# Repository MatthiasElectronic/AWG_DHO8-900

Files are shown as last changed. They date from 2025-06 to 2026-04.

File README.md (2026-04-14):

Artificial Waveform Generator for DHO800 and DHO900 series
===

This is a daughter board for the Rigol DHO800 or DHO900 series oscilloscopes to add the missing hardware for the function generator.  
State: finished and working

[Download all files as zip archive here](https://github.com/MatthiasElectronic/AWG_DHO8-900/archive/refs/heads/main.zip)

Discussion thread: https://www.eevblog.com/forum/testgear/awg-function-generator-for-dho800-900-series-oscilloscopes/

Hands-On video by Thomas from "hochohmig": https://www.youtube.com/watch?v=W03NUFdP6oc

Top_View
bottom_view
Overview

Table of Contents
===
1. [Target of this project](#target-of-this-project)
2. [Versions](#versions)
3. [Performance](#performance)
4. [Requirements](#requirements)
5. [Cost and Ordering](#cost-and-ordering)
6. [Interface between Mainboard and AWG daughter board](#interface-between-mainboard-and-awg-daughter-board)
7. [Topology discussion and design decisions](#topology-discussion-and-design-decisions)
8. [Possible Improvements](#possible-improvements)
9. [Thanksgiving](#thanksgiving)
10. [Disclaimer](#disclaimer)

Target of this project
-------
1. This is NOT a copy of the original function generator, but it uses the same interface and same DAC.
2. This design is optimized for cheap production including assembly, by the minimizing the amount of "extended components" from the JLCPCB manufacturer.
3. Minimizing distortion (THD) and noise (SNR) is achieved.
4. The ADC output filter is designed for better pulse and step response, therby having worse anti-alias attenuation (for >10MHz signals) and slight passband signal attenuation
5. Gain and offset tolerances are worse. A significant contributor is anyhow on the oscilloscope mainboard, so perfection cannot be achieved. However, if unlucky, tolerances in this project can mathematically hit quite hard.
6. As the original AWG, this function generator is designed for a 50 OHm coax cable with high impedance termination.

Versions
-------
V1: Original version, not recommended due to an offset bug and smaller mechanical misalignments.  
V2: Second version, not recommended due to a bug with OPA2673 sometimes getting hot. The fix with V3 is to connected Pins A0 and A1 to GND instead of -6.5V.  
V3: Recommended version.  
More details are in the history page in the schematic.

Performance
---
All signals are created with this AWG board, mounted on a DHO804 with a DHO924S vendor.bin.  
Measured on V1 PCB with the modifications of the V2 schematic.  

### Switching edges of a rectangular waveform
The switching edges are clean. trise & tfall are 15.5ns. This is a picture of maximum amplitude (+/-5V), but rise and fall times were measured identical for smaller voltages.  
Rect

### Bandwidth
The -3dB point is slightly above 25MHz. At the maximum selectable frequency of 25MHz, a peak-to-peak voltage of 719mV is measured, which is just above the 707mV of the -3dB point.  
Bandwidth

### Distortion / THD
Distortion is over the most parts independent from the amplitude, just at very small amplitudes this is different.  
Here, a measurement of a 1kHz sine signal at 10V and 100mV peak-to-peak voltage is provided.  
At 10Vpp, the dominant HD3 is at ca. -62dB, so THD should be below -60dB.  
Distortion_10V
Distortion_100mV

### Noise / SNR
**Noise measurement setup:**  
A sine signal at very low frequency is applied, the trigger is set to the crossover and the horizontal range is small such that the signal appears as DC.  
→ This way, AC RMS can be measured and equals the RMS noise at that signal amplitude. However, ultra low frequency noise is not visible.

**Noise at 2Vpp signal amplitude:**  
Noise_2V_Coax  
Noise RMS = 334µV, Signal RMS = 707mV => SNR = 67dB

**Noise at 10Vpp signal amplitude:**  
Noise_AWG_On_10V  
Noise RMS = 5.2mV, Signal RMS = 3.54V => SNR = 57dB

**Noise source**  
The measured noise levels are dominated by ripples/spikes from radiated EMI of the switching requlators on the mainboard with unshielded inductors.  
A 1.3MHz ripple is always present.  
A 740kHz ripple is only visible for >2Vpp, when the x10 gain stage (relay K4) is active..  
In the following FFT of a 10Vpp 1MHz sine signal, both ripples appear as peaks:  
Ripple_740kHz  
Luckily, this is coupled into the circuit before the attenuators, so at smaller signal amplitudes also the EMI ripple is attenuated.

In addition, there are random (burst mode) spikes clearling coming from the PSU brick. They can even be measured with the AWG switched off.  
Outside_Noise_Incoupling  

**To clarify: The noise/ripple is small enough, it is not visible in time domain unless having a very small amplitude.**

### Gain and Offset accuracy
My prototype has -3mV DC offset, coming directly from the motherboard on the target "DC offset" pin. This is the most noticable offset error, because this one is fully visible at the smallest signal amplitudes.  
Fixed this for my board, but this is completely related to tolerance. Additional offset errors are given in dependency of the AC gain and range selection, also this is amplified by 10 when the output signal exceeds 1Vp.  

My oscilloscope mainboard has a gain error of 3% between highest and lowest gain reference value. This is the most dominant part of the gain error, so if there is a need to fix this tolerance, this has to be done specific for each oscilloscope.

Requirements
--------
**Change vendor.bin**  
To add this AWG to the oscilloscope, a modified vendor.bin (DHO914S or DHO924S) to enable the AWG software functionalities is required.
https://www.eevblog.com/forum/testgear/hacking-the-rigol-dho800900-scope/msg5344076/#msg5344076

**Offset Removal**  
After modifying the vendor.bin, a DC offset in the analog measurement channels is there and might even not be removable by recalibration.  
A firmware update AFTER changing the vendor.bin, followed by a recalibration helps. I assume that the FPGA fimware is changed during a firmware update in dependency of the vendor.bin.

**Hardware version resistors**  
Update: There is no need to change the resistors for version detection - both DHO800 and DHO900 series oscilloscopes work without changing resistors.

**Add missing components to the mainboard**  
The DHO800 series oscilloscopes are missing some parts on the mainboard.  
- The connectors (1.27mm female sockets) 2x20 and 2x5 have to be added (this might be helpful, thanks to Mechatrommer: https://www.youtube.com/watch?v=dBg6KQtSWTM)
- Two OP Amps (3PEAK TP1282L1-VR) have to be added for the offset and gain analog values. These are not really suited for this operation (because they are not officially input rail-rail), but somehow this still works and they are also placed on the original DHO900 series.
- The BNC connector is missing, but as this part is extremely high and nowhere to find, I instead increased the AWG PCB size and simply mounted a smaller BNC connector on the AWG board. So no extra BNC connector on the mainboard. When soldering the BNC connector onto the daughterboard, I suggest to do this as the last step. The SMD PCB interconnects have some tolerance and also the BNC connector ideally should not be pushed completely into the PCB to achieve the same height as the "trigger out" from the mainboard. I aligned the connector before soldering with the AWG daughterboard mounted on the mainboard.
- The board needs to be fixed to the mounting holes. M4 screws with two M4 fasteners were sufficient, but are slightly too large (soldermask IS the isolation...). A better solution (idea from hochohmig.de) are solderable M3 through hole taps, this is cleaner and does not require access to the backside of the mainboard. Securing the daughterboard to the mainboard with the mounting holes is absolutely necessary, the PCB interconnects alone are not sufficient as the BNC connector is not fastened to the case.
- A hole needs to be drilled in the plastic casing for the BNC connector.  
unplaced
OP_AMPs
placed  
BNC_inside
BNC_outside
through_hole_tap

Luckily, all remaining components (resistors, reference voltages, digital interface, …) are already assembled.

**It is NOT necessary to add any additional RAM to the DHO800 series.**

Cost and Ordering
-------
Total cost for 1 board should be ca. 50€.

All components (apart from the connectors) are soldered on the top layer. The PCB is a four layer board.  
This allowed economic assembly with JLCPCB (not sponsored), which is very cheap when using the preferred components. So the whole design is optimized around these preferred components to keep cost low. However, there are some components that are extended (and this costs ca. 3€ each extra). So most of them were ordered on LCSC, because this order was anyways necessary for the connectors and the OP-Amps on the main board.
All parts in this design files have a LCSC number, which makes ordering at LCSC or JLCPCB very simple.
Just be sure that you
1. Have a hot air station or let the QFN packages be soldered (DAC & OP-Amp). Even when ignoring the bottom central GND-pad, this won’t be easy with a simple soldering iron.
2. Use a four layer bord with the recommended or a similar stackup as documented on the first page of the schematic to have somewhat correct impedances.
3. Have accessable vias such that you can use them as measurement points if something does not work.
4. Do not choose a different inductor with a larger height for the step down converters, as there is no space to the casing.

When keeping extended components low (I only chose the SMD inductor), then this can be quite cheap. I ended up with 34€ on JLCPCB for 5 partly assembled boards and 41€ on LCSC for components for 2 boards, including tax and shipment. This adds up to 75€. It should be ca. 53€ if I only ordered components for 1 board. (05/2025)

Interface between Mainboard and AWG daughter board
----
CLK = Sample rate = 156MHz  
The digital data is ALWAYS completely using up the headroom of the DAC.  
Adjustments on the gain are only done by the analog gain input voltage, not digitally.  
With Amplitude = Vpp set to 2V, all attenuation/amplification stages K1-K4 are disabled and the analog gain input is at its maximum value.  
Still unclear is the "Protection" output signal, also it seems strange that this has to be pulled down to negative voltage.  
The 5 relays are: /sqrt(10), /10, /10, *10, On/Off

Topology discussion and design decisions
---
The topolology is  
Topology_updated

The DAC itself is the same as on the original AWG board, but in a much cheaper QFN package. The allowed DAC output current was significantly overdriven in the original design, thus I reduced this current.

The OP amps are completely exchanged in favor for the price. The original 1GHz part just seemed to be overkill for a 50MHz signal generator. I chose the 230MHz OPA2673 instead. Sadly, there is nothing cheap in between that has high voltage and high bandwith. But the slew rate is sufficient.

Power rails are reduced to only +6.5V and -6.5V, which is just sufficient for the maximum +5V / -5V signal output voltage and at the border of the allowed OP amp operating conditions. These are both switchers, ripple is kept low by having forced PWM and filtering directly at the OP amp inputs. There is no need for LDOs as most LDOs cannot remove the 1.1MHz ripple. The 5V relays are rated for this voltage, so this is great as well.
Although the original board had +15V/-12V, the same maximum output signal is achieved. Having only 6.5V means that the DC offset stage had to be redone, therefore all PI attenuators and OP amp gains had to be changed. As an easy addon, I also added matched impedances on the PCB.

The DAC output filter is completly redone. The original filter required very specific and uncommon component values, which are nowhere availlable, so this had to be completely changed.

In the original design there was a 9th oder elliptic filter, which sounds great for HF suppression, but has a terrible step response. As I wanted solid edges for rectangular signals, I opted for a filter with a much better phase. While also optimizing for minimum component variation, this turned out to be a bit „creative“ and a 5th order lowpass filter (somewhere in between butterworth and bessel). Simulation in Spice looked promising, but the measured edges (see above, trise/fall = 15.5ns) are slightly slower than simulated (10ns).

As can be seen below, the step response is much better while not exceeding the OP ampl slew rate. Looking at the attenuation over frequency, obviously the elliptic filter is better. My filter has a slight attenuation in the upper passband and a not so perfect attenuation at the sample frequency (156MHz).

Attenuation in the passband: This is noticable for frequencies above 10MHz, but can be corrected for sine signals by manually adjusting the amplitude.

Aliasing: Aliasing can only occur above the Nyquist frequency (78MHz). For signals with lower frequencies (e. g. <1MHz), where fsig << fsample, this is not important as the sinc-behavior in the frequency domain of the sample and hold circuit does sufficently suppress any aliasing (sinc(1-1MHz/156MHz)=-44dB), in addition to the lowpass attenuation. For larger frequencies, this will be worse and probably noticable in the FFT or a spectrum viewer.

Conclusion:  
→ a worse aliasing attenuation, relevant only at high frequencies
→ a better behavior in the step and impulse response

filter

Possible Improvements
---
...which I am not going to solve, but feel free to contribute.  
- the M4 fasteners are too large, more space is required as the solder mask is currently the only line of defence.  
- a DC offset potentiometer would be helpful  
- improve the gain accuracy, but this can get very difficult  
- choose connectors with through-hole alignment pins for easier assembly, but this might require better measurement of the dimensions.
- Eliminate the magnetic EMI incoupling of the switching regulators on the mainboard. Easiest solution could be swapping layer 3 (GND) and layer 4 (signal) and correcting trace widths for the impedances.
  However, as this is magnetic near field, this might not be sufficent. I tried some aluminum kitchen foil connected to GND as a shield, which brought -3dB. A floating thin iron sheet brought -10dB.
  Another option could be to replace the unshielded inductors on the main board with shielded ones.

Be warned that on the left hand side from the relays, the plastic case gets very close to the PCB, so even large MLCCs or SMD inductors can be too large and the relays definitly are.

Thanksgiving
---
Thanks to  
Everybody contributing to the [Hacking the Rigol DHO800/900 Scope](https://www.eevblog.com/forum/testgear/hacking-the-rigol-dho800900-scope/) thread  
Pu6k1n [EEVBlog] for the [schematic of the reverse-engineered original AWG](https://www.eevblog.com/forum/testgear/hacking-the-rigol-dho800900-scope/?action=dlattach;attach=2492911), the pinning helped a lot  
AndyBig [EEVBlog] for all information about DHO800 to DHO900 vendor.bin modification and reporting a bug with V2  
Mechatrommer [EEVBlog] for inspiration from his own AWG attempt and lots of tiny information  
Thomas from [hochohmig.de](https://www.hochohmig.de/) for providing calculation tools, testing the board and creating a [demonstration video - check out his channel](https://www.youtube.com/watch?v=W03NUFdP6oc&t=1s)  
Contributers to KiCad and the library plugins

Disclaimer
---
This is published with CERN-OHL-W-2.0 license, which is accessible in license.txt.
No liability is provided for this not working or causing any form of damage or harm. This is not a product, but a development board. Use at your own risk.  
This project is influenced by the original AWG from Rigol, so only recommended for personal use. Although not checked, selling this AWG could possibly violate patents or rights of Rigol.

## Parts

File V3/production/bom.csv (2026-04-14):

Designator | Footprint | Quantity | Value | LCSC Part #
C201, C202, C203, C209, C210, C305, C310, C312, C313, C315, C321, C323, C324, C325, C326, C328, C401, C404, C405, C501, C505 | C_0603 | 21 | 100nF | C14663
C204, C205, C206, C211, C212, C213, C304, C309, C311, C314, C322, C327, C402, C403 | C_0805 | 14 | 10uF | C15850
C207, C208, C214, C215, C216, C217 | C_1206 | 6 | 47uF | C96123
C301, C302 | C_0603 | 2 | 10pF | C1634
C303, C306 | C_0603 | 2 | 68pF | C28262
C317, C318, C320, C329 | C_0603 | 4 | 100pF | C14858
C406, C409, C410, C411, C412, C413, C502, C503 | C_0603 | 8 | 1uF | C15849
C407, C408, C504 | C_0603 | 3 | 47pF | C1671
D301, D302, D401, D402, D403, D404, D405, D406, D407, D408, D501 | SOT-23-3_L2.9-W1.3-P1.90-LS2.4-BR | 11 | BAV99_C7420336 | C7420336
FB201, FB202, FB203 | FB_0805 | 3 | ~ | C1015
J101 | BNC_Amphenol_ICC 031-5329-51RFX | 1 | BNC_Amphenol_ICC 031-5329-51RFX | C5443992
K1, K2, K3, K4, K5 | RELAY-SMD_G6K-2F-X-XX | 5 | ~ | C47190
L201, L202 | L_APV_ANR5045 | 2 | 22uH | C440232
L301, L302, L303, L304, L305, L306, L307, L308, L309, L310, L311, L401 | L_0603 | 12 | 100nH | C98088
Q201, Q301 | Q_SOT-23 | 2 | MMBT3906 | C7420354
Q202, Q401, Q402, Q403, Q404, Q405 | Q_SOT-23 | 6 | BC846B | C20069134
R101, R504 | R_0603 | 2 | 1kΩ | C21190
R103 | R_0603 | 1 | 0Ω | C21189
R201, R207 | R_0603 | 2 | 24kΩ | C23352
R202, R205, R206, R210, R212, R435, R436, R440, R441, R442 | R_0603 | 10 | 22kΩ | C31850
R203, R208, R209, R408, R433, R434, R437, R438, R439, R502, R507 | R_0603 | 11 | 3.3kΩ | C22978
R204, R211, R318, R443, R444, R445, R446, R447 | R_0603 | 8 | 68Ω | C27592
R301, R406 | R_0603 | 2 | 4.7Ω | C23164
R302, R315 | R_0603 | 2 | 5.6kΩ | C23189
R303, R314, R427, R428 | R_0603 | 4 | 390Ω | C23151
R304, R430, R431 | R_0603 | 3 | 56Ω | C25196
R305, R311 | R_0603 | 2 | 49.9Ω | C23185
R306, R312, R316 | R_0603 | 3 | 2.7kΩ | C13167
R307, R310, R317, R319, R422, R423, R424, R425 | R_0603 | 8 | 100Ω | C22775
R308, R313 | R_0603 | 2 | 560Ω | C23204
R401, R419, R420 | R_0603 | 3 | 4.7kΩ | C23162
R402, R405, R409 | R_0603 | 3 | 15Ω | C22810
R403, R505, R508 | R_0603 | 3 | 100kΩ | C25803
R404 | R_0805 | 1 | 270Ω | C17590
R407 | R_0603 | 1 | 4.3kΩ | C23159
R410, R413 | R_1206 | 2 | 100Ω | C17901
R414, R415, R416, R417 | R_0603 | 4 | 10Ω | C22859
R418, R421, R432, R460 | R_0603 | 4 | 180Ω | C22828
R426 | R_0603 | 1 | 47Ω | C23182
R429 | R_0603 | 1 | 6.8kΩ | C23212
R455 | R_0603 | 1 | 82Ω | C23255
R457 | R_1206 | 1 | 120Ω | C17909
R458 | R_0603 | 1 | 1.8kΩ | C4177
R501, R506 | R_0603 | 2 | 3.9kΩ | C23018
R503 | R_0603 | 1 | 5.1kΩ | C23186
U201, U202 | SOT-23-6 | 2 | LMR54406FDBVR | C3193129
U301 | Texas_RSA_VQFN-16-1EP_4x4mm_P0.65mm_EP2.7x2.7mm | 1 | OPA2673IRGVR | C1848168
U302 | LFCSP-32_L5.0-W5.0-P0.50-BL-EP3.1 | 1 | AD9744ACPZRL7 | C514295
U303 | SOIC-8_L4.9-W3.9-P1.27-LS6.0-BL | 1 | NE5532DR | C7426
U501 | SOIC-8_3.9x4.9mm_P1.27mm | 1 | LM393DR2G | C7955
X1 | PinHeader_2x20_P1.27mm_Vertical_SMD | 1 | Conn_02x20_1.27mm_SMD_Header_M | C2881925
X2 | PinHeader_2x05_P1.27mm_Vertical_SMD | 1 | Conn_02x05_1.27mm_SMD_Header_M | C2881910

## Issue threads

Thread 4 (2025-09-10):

What is U302?

Kabron287, 2025-09-10:
What is U302?

MatthiasElectronic, 2025-09-14:
U302 is AD9744ACPZRL7.
It was not visible in the schematic, also not in the BOM. Thanks for the feedback, I just fixed that for V2.

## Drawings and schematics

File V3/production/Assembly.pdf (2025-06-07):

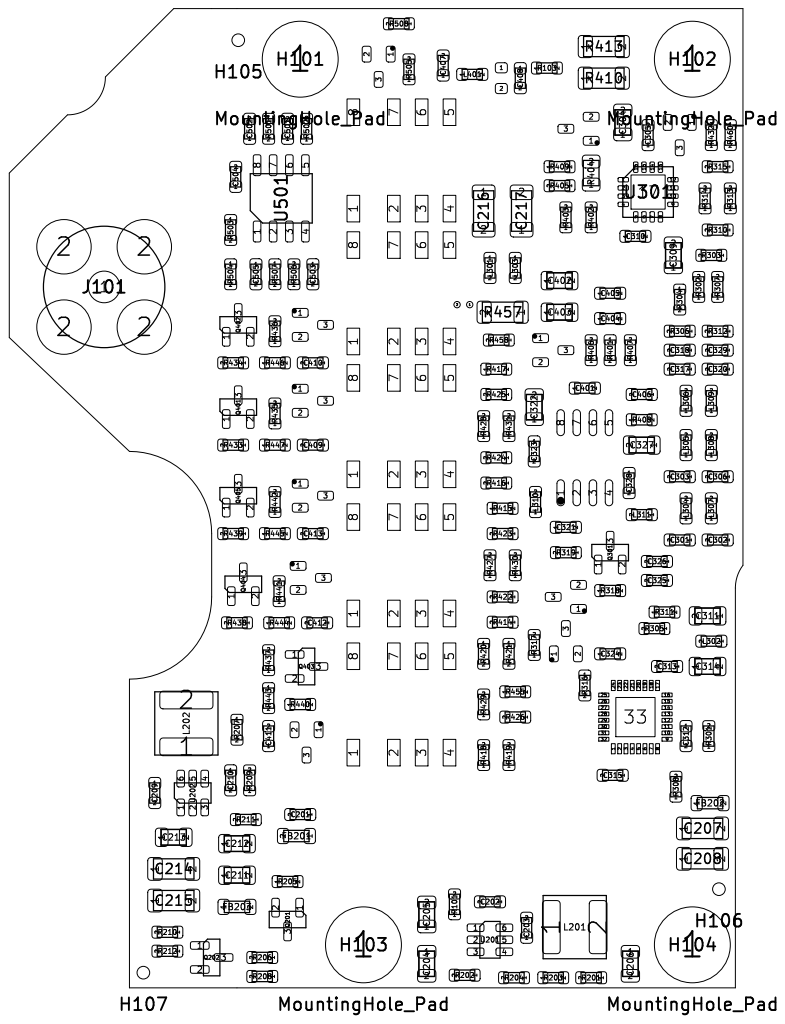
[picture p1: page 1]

File: AWG.kicad_pcb Sheet: M. Zimmermann

Id: 1/1 Title: AWG for DHO8/900

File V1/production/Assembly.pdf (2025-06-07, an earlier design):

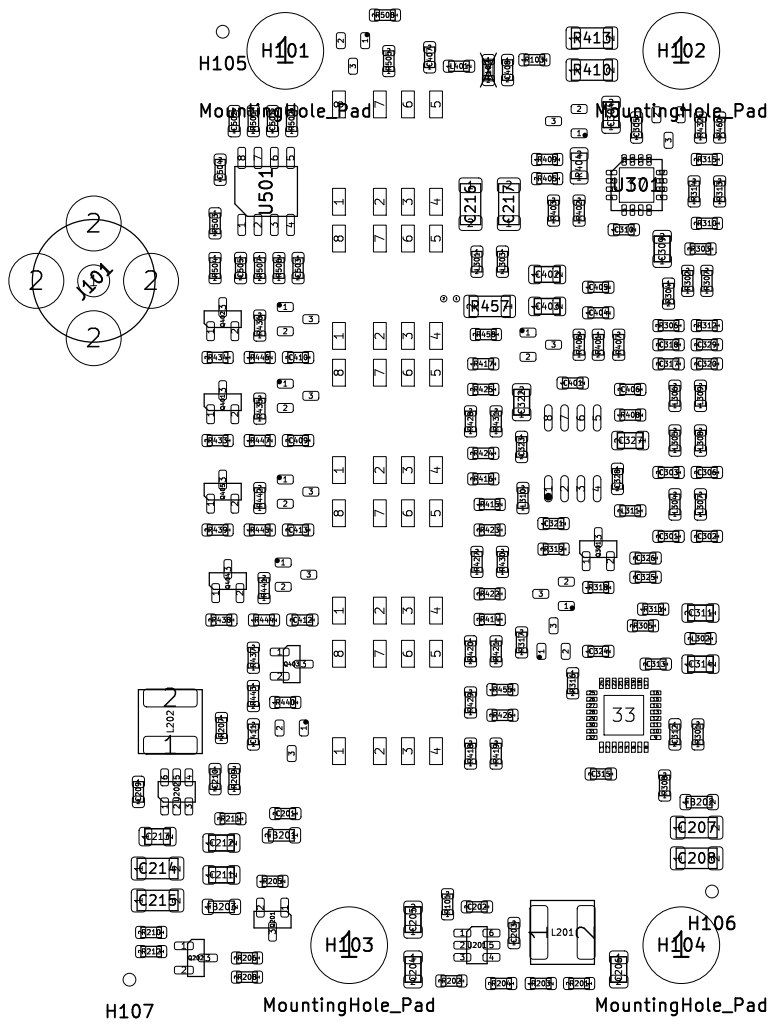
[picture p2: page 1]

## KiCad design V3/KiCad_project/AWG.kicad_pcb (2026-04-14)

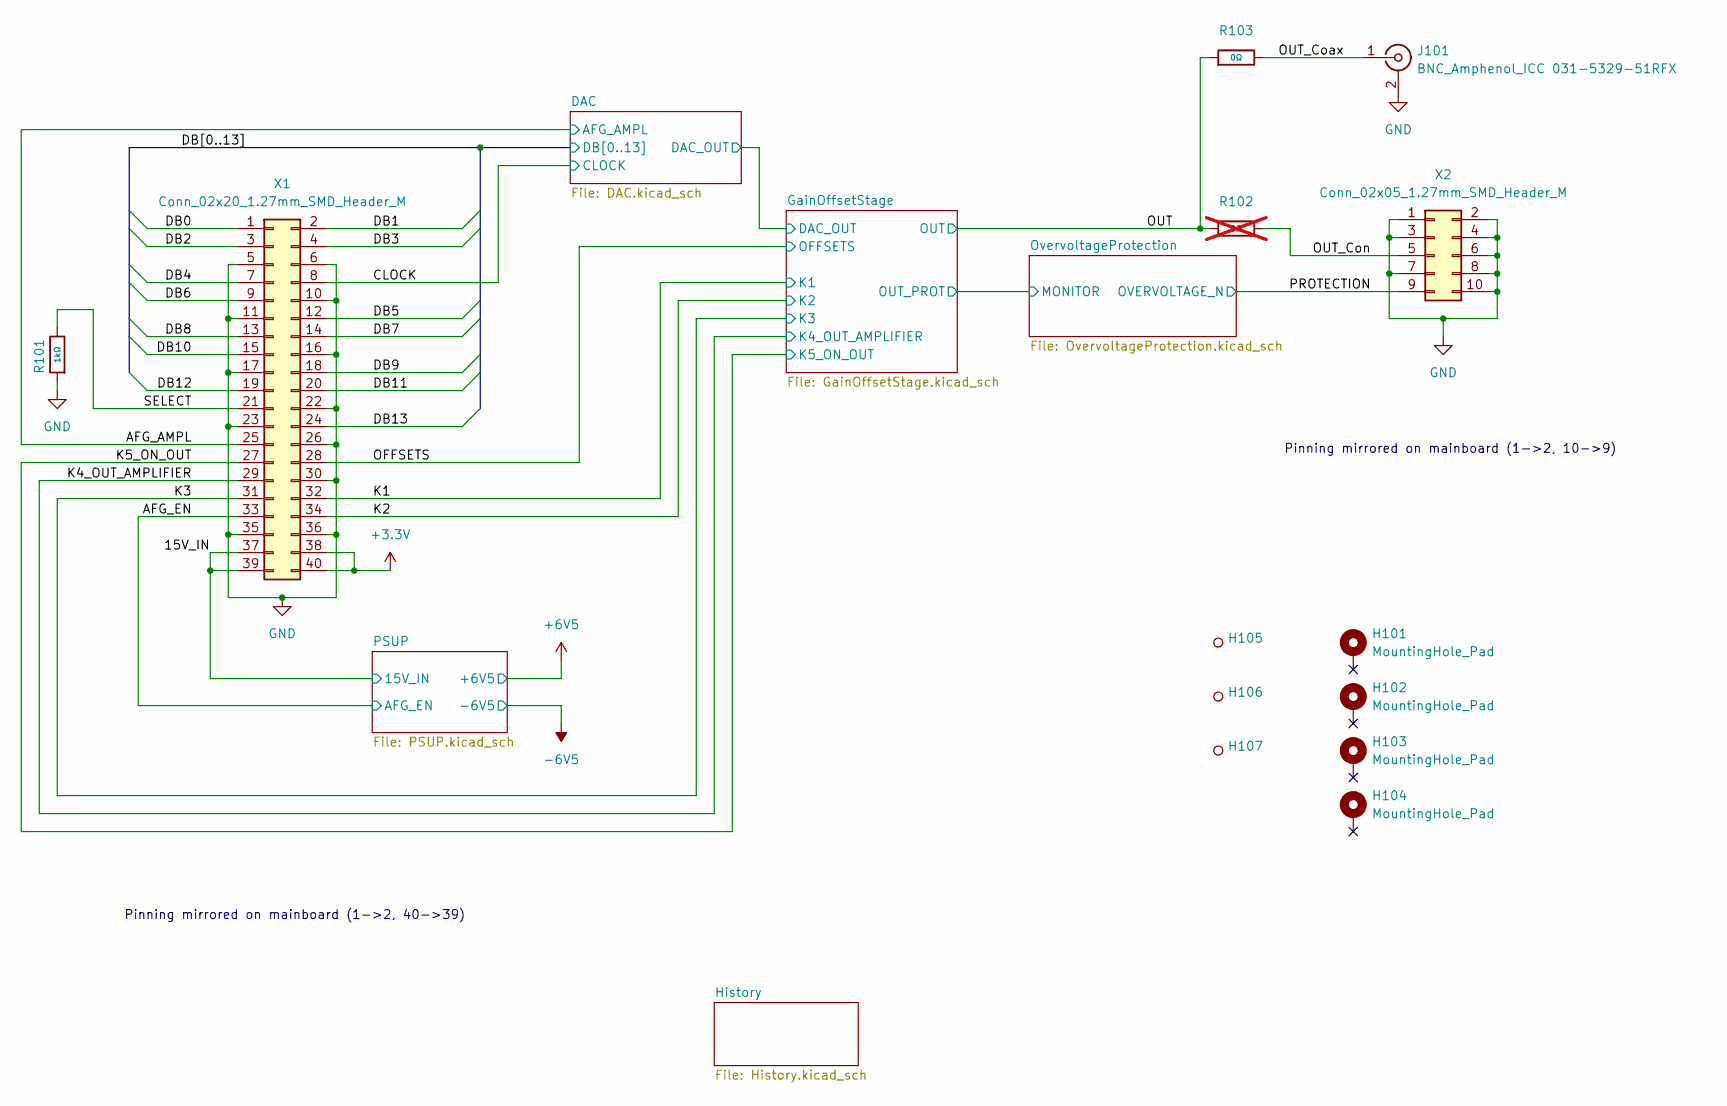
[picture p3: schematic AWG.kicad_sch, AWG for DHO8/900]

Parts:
H101, H102, H103, H104: MountingHole_Pad; MountingHole_4.0mm_SmallPad
H105, H106, H107: Hole_Tooling_JLCPCB
J101: BNC_Amphenol_ICC 031-5329-51RFX; LCSC C5443992
R101: 1kΩ; R_0603; Overload Voltage (Max) 75V; Tolerance ±1%; Part 0603WAF1001T5E; LCSC C21190
R102: 0Ω; R_0603; Overload Voltage (Max) 75V; Tolerance ±1%; Part 0603WAF0000T5E; LCSC C21189; not fitted
R103: 0Ω; R_0603; Overload Voltage (Max) 75V; Tolerance ±1%; Part 0603WAF0000T5E; LCSC C21189
X1: Conn_02x20_1.27mm_SMD_Header_M; PinHeader_2x20_P1.27mm_Vertical_SMD; LCSC C2881925
X2: Conn_02x05_1.27mm_SMD_Header_M; PinHeader_2x05_P1.27mm_Vertical_SMD; LCSC C2881910

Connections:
+3.3V: X1.38, X1.40; also elsewhere on the board
/15V_IN: X1.37, X1.39; also elsewhere on the board
/AFG_AMPL: X1.25; also elsewhere on the board
/AFG_EN: X1.33; also elsewhere on the board
/CLOCK: X1.8; also elsewhere on the board
/DB0: X1.1; also elsewhere on the board
/DB1: X1.2; also elsewhere on the board
/DB2: X1.3; also elsewhere on the board
/DB3: X1.4; also elsewhere on the board
/DB4: X1.7; also elsewhere on the board
/DB5: X1.12; also elsewhere on the board
/DB6: X1.9; also elsewhere on the board
/DB7: X1.14; also elsewhere on the board
/DB8: X1.13; also elsewhere on the board
/DB9: X1.18; also elsewhere on the board
/DB10: X1.15; also elsewhere on the board
/DB11: X1.20; also elsewhere on the board
/DB12: X1.19; also elsewhere on the board
/DB13: X1.24; also elsewhere on the board
/K1: X1.32; also elsewhere on the board
/K2: X1.34; also elsewhere on the board
/K3: X1.31; also elsewhere on the board
/K4_OUT_AMPLIFIER: X1.29; also elsewhere on the board
/K5_ON_OUT: X1.27; also elsewhere on the board
/OFFSETS: X1.28; also elsewhere on the board
/OUT: R102.1, R103.1; also elsewhere on the board
/OUT_Coax: J101.1 (In), R103.2
/OUT_Con: R102.2, X2.5
/PROTECTION: X2.9; also elsewhere on the board
/SELECT: R101.2, X1.21
GND: J101.2 (Ext), R101.1, X1.5, X1.6, X1.10, X1.11, X1.16, X1.17, X1.22, X1.23, X1.26, X1.30, X1.35, X1.36, X2.1, X2.2, X2.3, X2.4, X2.6, X2.7, X2.8, X2.10; also elsewhere on the board

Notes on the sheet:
Pinning mirrored on mainboard (1->2, 40->39)
Pinning mirrored on mainboard (1->2, 10->9)

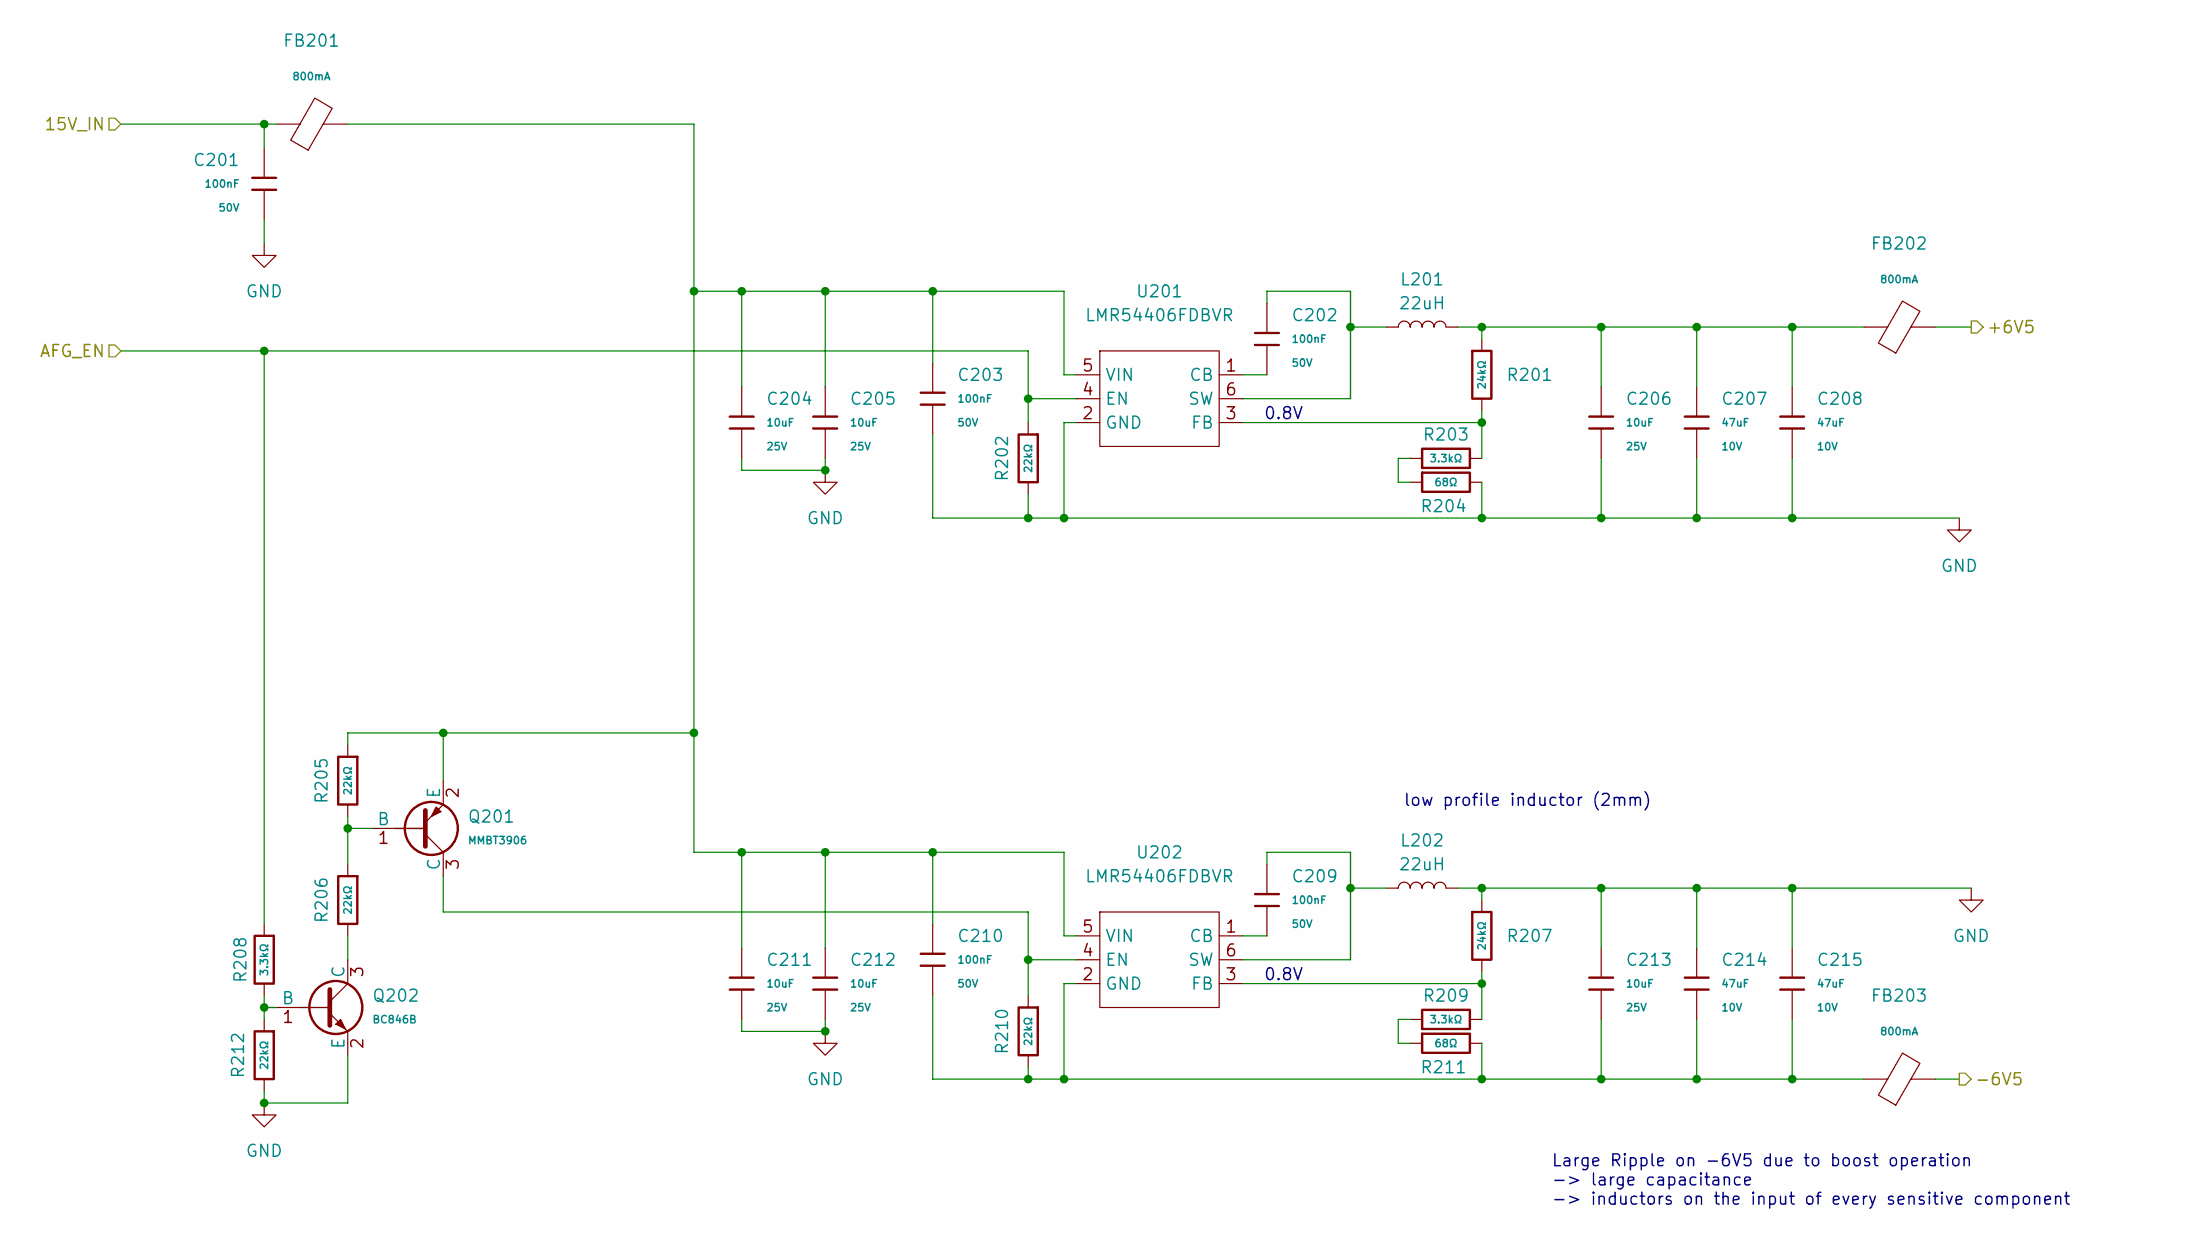
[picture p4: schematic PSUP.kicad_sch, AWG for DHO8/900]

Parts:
C201, C202, C203, C209, C210: 100nF; C_0603; Voltage Rated 50V; Tolerance ±10%; Part CC0603KRX7R9BB104; LCSC C14663
C204, C205, C206, C211, C212, C213: 10uF; C_0805; Voltage Rated 25V; Tolerance ±10%; Part CL21A106KAYNNNE; LCSC C15850
C207, C208, C214, C215: 47uF; C_1206; Voltage Rated 10V; Tolerance ±20%; Part CL31A476MPHNNNE; LCSC C96123
FB201, FB202, FB203: FB_0805; Current Rating 800mA; Tolerance ±25%; Part GZ2012D101TF; LCSC C1015
L201, L202: 22uH; L_APV_ANR5045; LCSC C440232
Q201: MMBT3906; Q_SOT-23; Part MMBT3906; LCSC C7420354
Q202: BC846B; Q_SOT-23; Part BC846B; LCSC C20069134
R201, R207: 24kΩ; R_0603; Overload Voltage (Max) 75V; Tolerance ±1%; Part 0603WAF2402T5E; LCSC C23352
R202, R205, R206, R210, R212: 22kΩ; R_0603; Overload Voltage (Max) 75V; Tolerance ±1%; Part 0603WAF2202T5E; LCSC C31850
R203, R208, R209: 3.3kΩ; R_0603; Overload Voltage (Max) 75V; Tolerance ±1%; Part 0603WAF3301T5E; LCSC C22978
R204, R211: 68Ω; R_0603; Overload Voltage (Max) 75V; Tolerance ±1%; Part 0603WAF680JT5E; LCSC C27592
U201, U202: LMR54406FDBVR; SOT-23-6; Manufacturer Part LMR54406FDBVR; LCSC C3193129

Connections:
+6V5: FB202.2; also elsewhere on the board
-6V5: FB203.2; also elsewhere on the board
/15V_IN: C201.1, FB201.1; also elsewhere on the board
/AFG_EN: R202.1, R208.1, U201.4 (EN); also elsewhere on the board
GND: C201.2, C203.2, C204.2, C205.2, C206.2, C207.2, C208.2, C211.2, C212.2, C213.1, C214.1, C215.1, L202.2, Q202.2 (E), R202.2, R204.2, R207.1, R212.2, U201.2 (GND); also elsewhere on the board
unnamed: C206.1, C207.1, C208.1, FB202.1, L201.2, R201.1
unnamed: Q201.1 (B), R205.2, R206.1
unnamed: Q201.3 (C), R210.1, U202.4 (EN)
unnamed: C203.1, C204.1, C205.1, C210.1, C211.1, C212.1, FB201.2, Q201.2 (E), R205.1, U201.5 (VIN), U202.5 (VIN)
unnamed: Q202.1 (B), R208.2, R212.1
unnamed: Q202.3 (C), R206.2
unnamed: R203.1, R204.1
unnamed: R209.1, R211.1
unnamed: C202.2, U201.1 (CB)
unnamed: R201.2, R203.2, U201.3 (FB)
unnamed: C202.1, L201.1, U201.6 (SW)
unnamed: C209.2, U202.1 (CB)
unnamed: R207.2, R209.2, U202.3 (FB)
unnamed: C210.2, C213.2, C214.2, C215.2, FB203.1, R210.2, R211.2, U202.2 (GND)
unnamed: C209.1, L202.1, U202.6 (SW)

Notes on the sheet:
0.8V
Large Ripple on -6V5 due to boost operation -> large capacitance -> inductors on the input of every sensitive component
low profile inductor (2mm)

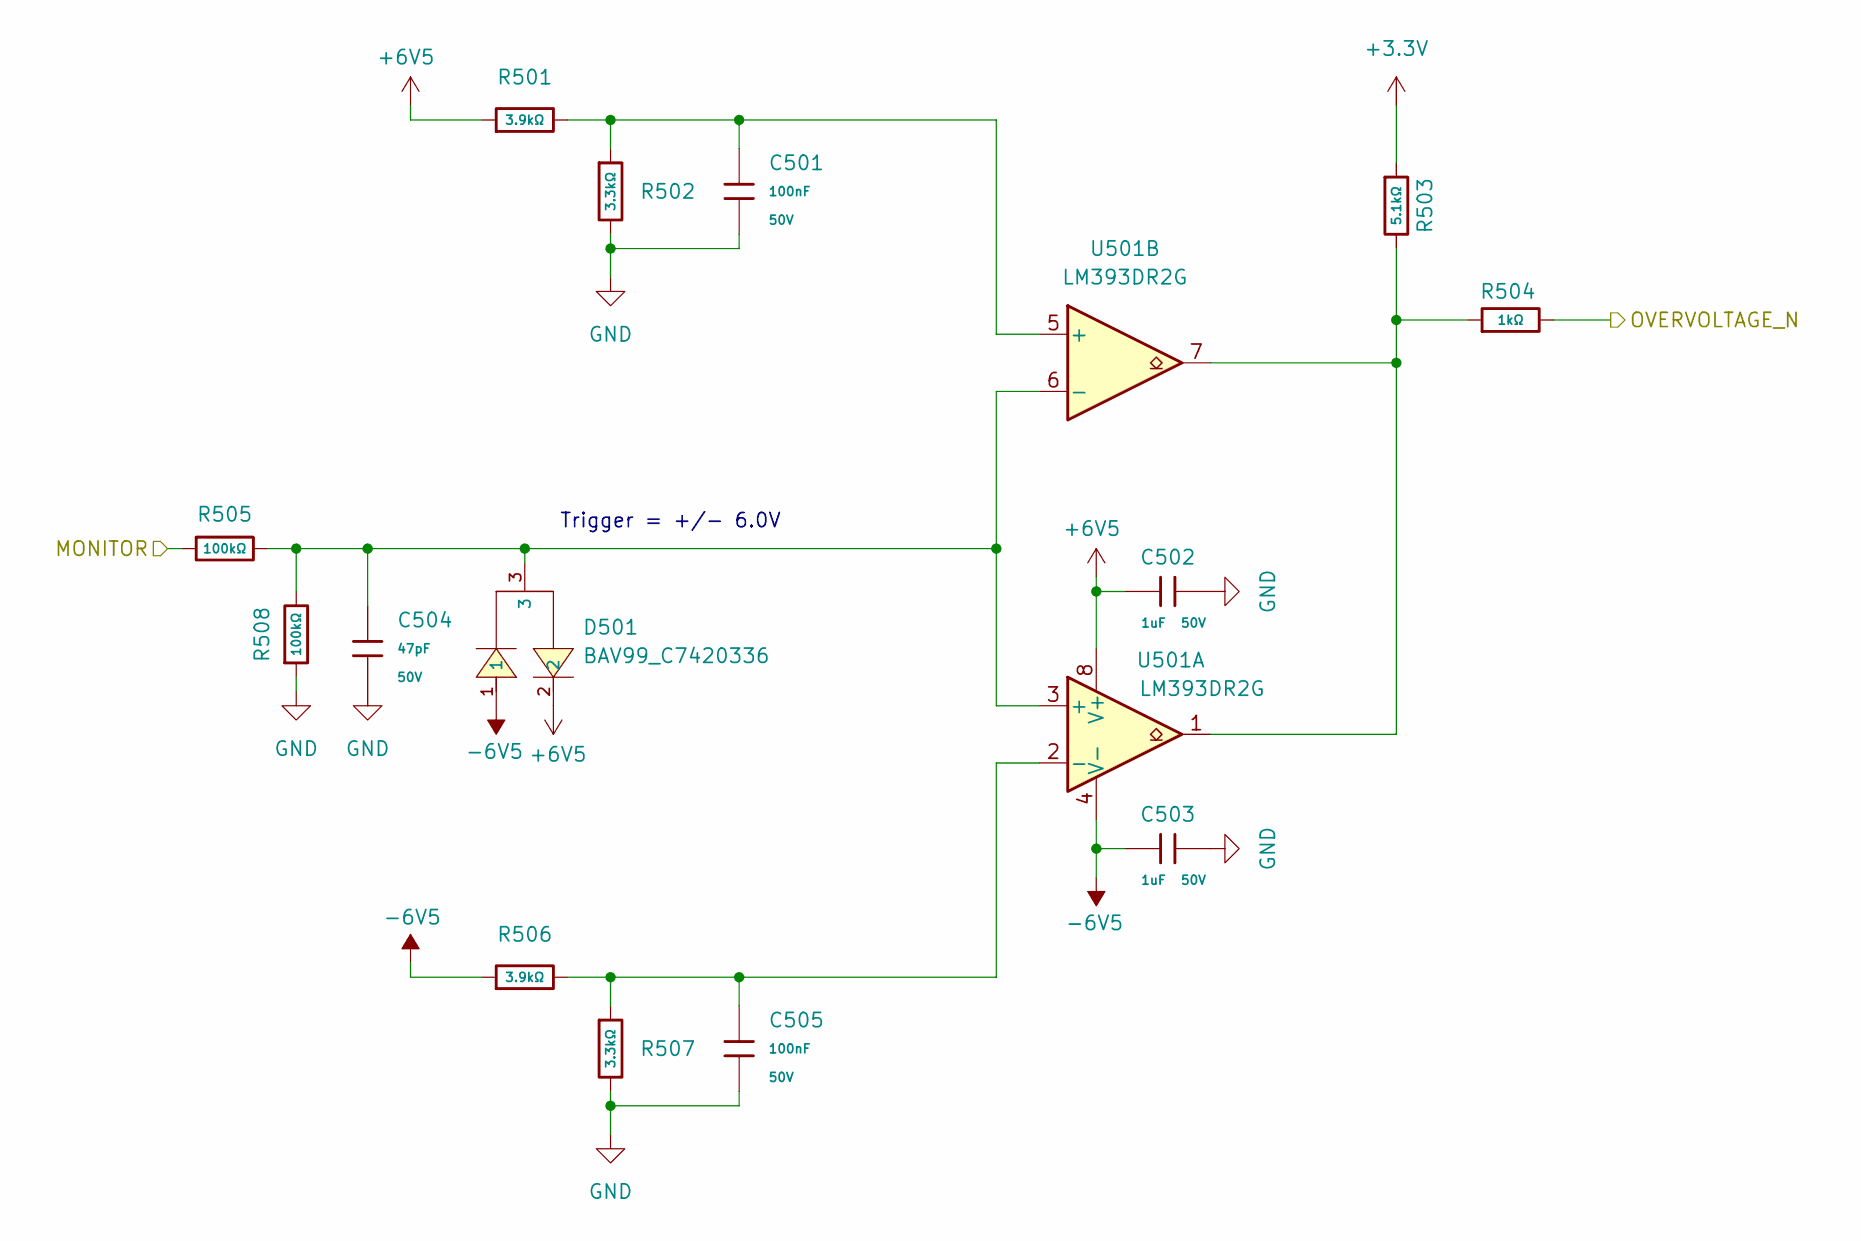
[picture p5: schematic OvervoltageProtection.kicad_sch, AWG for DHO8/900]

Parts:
C501, C505: 100nF; C_0603; Voltage Rated 50V; Tolerance ±10%; Part CC0603KRX7R9BB104; LCSC C14663
C502, C503: 1uF; C_0603; Voltage Rated 50V; Tolerance ±10%; Part CL10A105KB8NNNC; LCSC C15849
C504: 47pF; C_0603; Voltage Rated 50V; Tolerance ±5%; Part CL10C470JB8NNNC; LCSC C1671
D501: BAV99_C7420336; SOT-23-3_L2.9-W1.3-P1.90-LS2.4-BR; Reverse Voltage (Vr) 100V; Forward Voltage (Vf@If) 1.25V@150mA; Part BAV99; LCSC C7420336
R501, R506: 3.9kΩ; R_0603; Overload Voltage (Max) 75V; Tolerance ±1%; Part 0603WAF3901T5E; LCSC C23018
R502, R507: 3.3kΩ; R_0603; Overload Voltage (Max) 75V; Tolerance ±1%; Part 0603WAF3301T5E; LCSC C22978
R503: 5.1kΩ; R_0603; Overload Voltage (Max) 75V; Tolerance ±1%; Part 0603WAF5101T5E; LCSC C23186
R504: 1kΩ; R_0603; Overload Voltage (Max) 75V; Tolerance ±1%; Part 0603WAF1001T5E; LCSC C21190
R505, R508: 100kΩ; R_0603; Overload Voltage (Max) 75V; Tolerance ±1%; Part 0603WAF1003T5E; LCSC C25803
U501: LM393DR2G; SOIC-8_3.9x4.9mm_P1.27mm; LCSC C7955

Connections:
+3.3V: R503.1; also elsewhere on the board
+6V5: C502.1, D501.2, R501.1, U501.8 (V+); also elsewhere on the board
-6V5: C503.1, D501.1, R506.1, U501.4 (V-); also elsewhere on the board
/GainOffsetStage/OUT_PROT: R505.1; also elsewhere on the board
/PROTECTION: R504.2; also elsewhere on the board
GND: C501.2, C502.2, C503.2, C504.2, C505.2, R502.2, R507.2, R508.1; also elsewhere on the board
unnamed: R503.2, R504.1, U501.1, U501.7
unnamed: C504.1, D501.3, R505.2, R508.2, U501.3 (+), U501.6 (-)
unnamed: C505.1, R506.2, R507.1, U501.2 (-)
unnamed: C501.1, R501.2, R502.1, U501.5 (+)

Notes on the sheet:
Trigger = +/- 6.0V

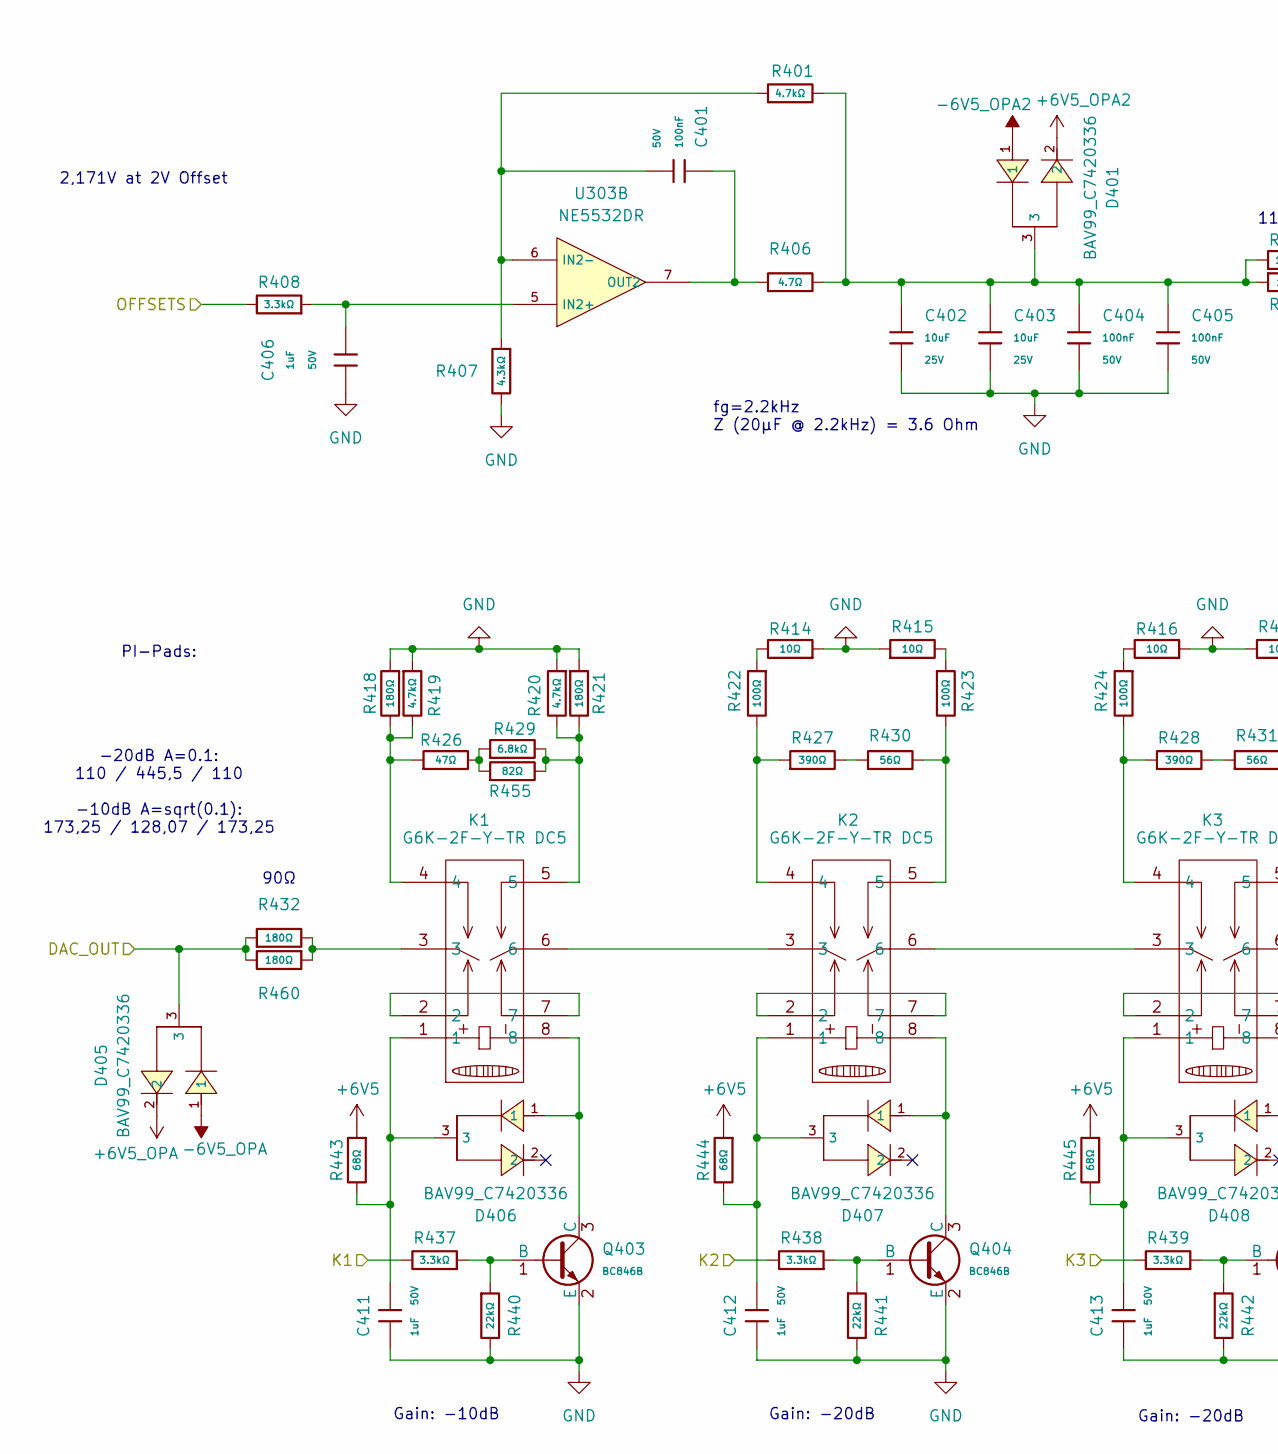
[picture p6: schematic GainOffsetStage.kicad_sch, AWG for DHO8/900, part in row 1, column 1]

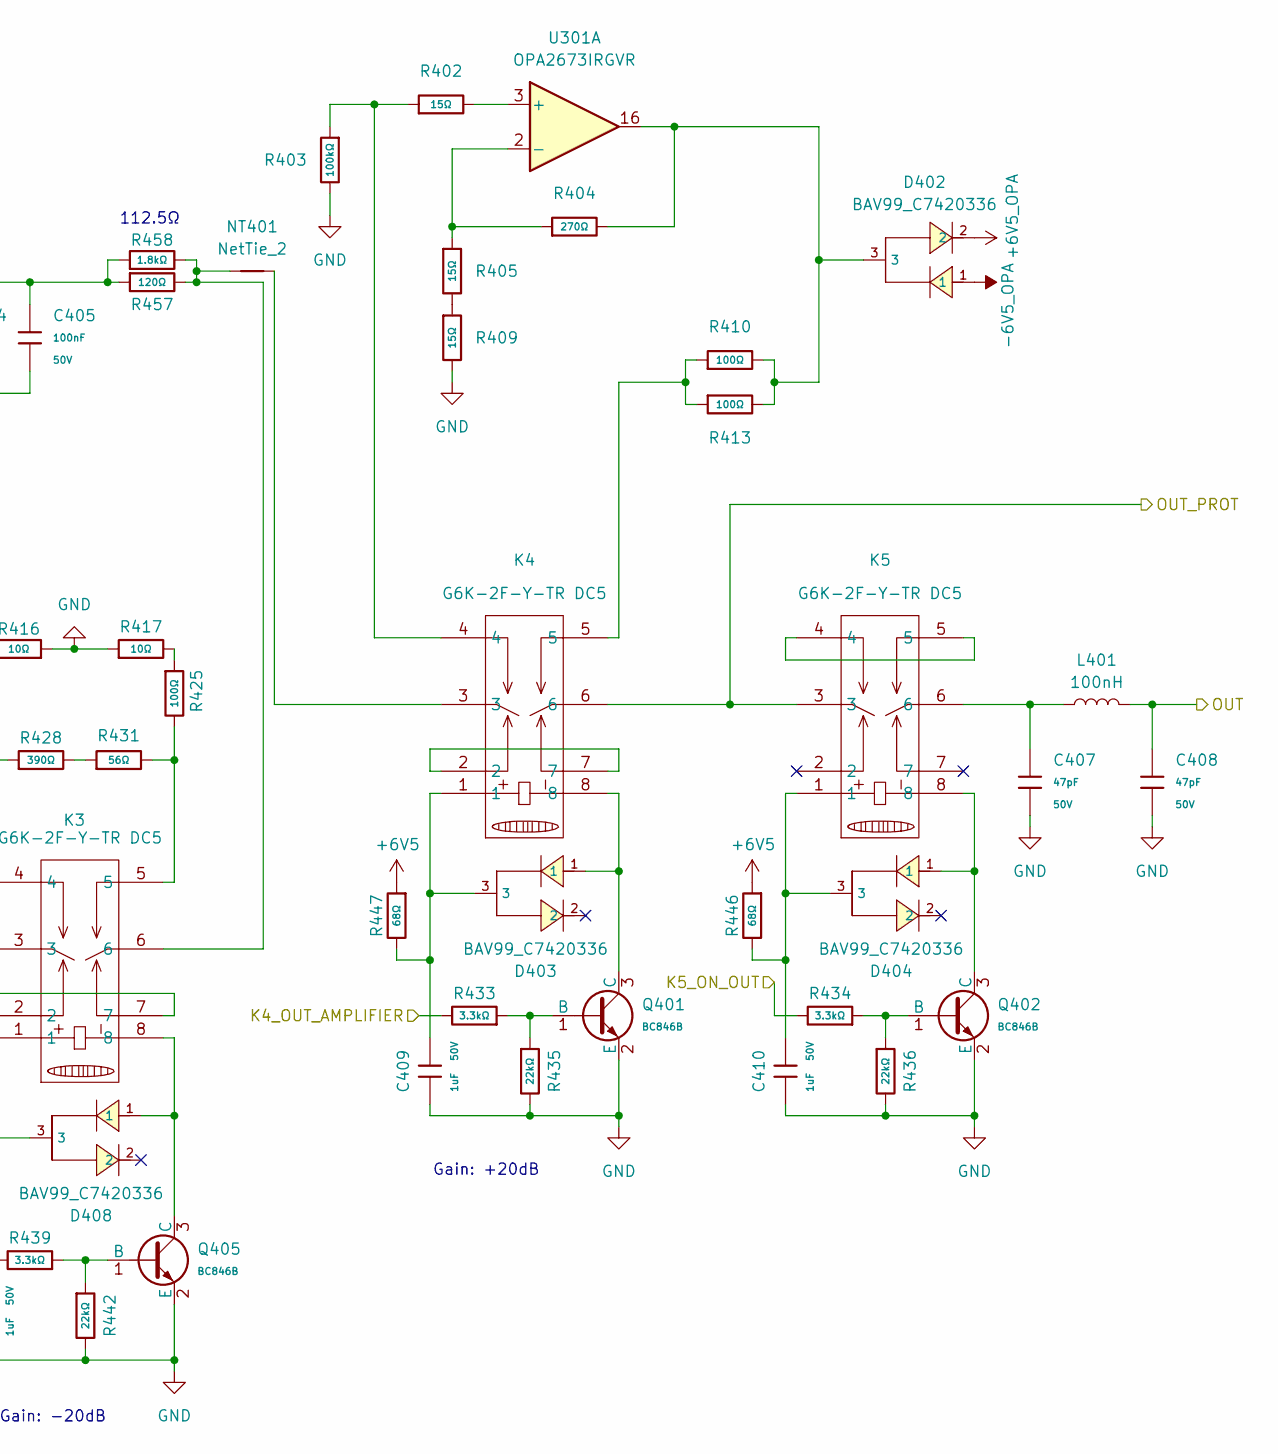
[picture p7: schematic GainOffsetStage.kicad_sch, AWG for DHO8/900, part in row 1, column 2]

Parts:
C401, C404, C405: 100nF; C_0603; Voltage Rated 50V; Tolerance ±10%; Part CC0603KRX7R9BB104; LCSC C14663
C402, C403: 10uF; C_0805; Voltage Rated 25V; Tolerance ±10%; Part CL21A106KAYNNNE; LCSC C15850
C406, C409, C410, C411, C412, C413: 1uF; C_0603; Voltage Rated 50V; Tolerance ±10%; Part CL10A105KB8NNNC; LCSC C15849
C407, C408: 47pF; C_0603; Voltage Rated 50V; Tolerance ±5%; Part CL10C470JB8NNNC; LCSC C1671
D401, D402, D403, D404, D405, D406, D407, D408: BAV99_C7420336; SOT-23-3_L2.9-W1.3-P1.90-LS2.4-BR; Reverse Voltage (Vr) 100V; Forward Voltage (Vf@If) 1.25V@150mA; Part BAV99; LCSC C7420336
K1, K2, K3, K4, K5: RELAY-SMD_G6K-2F-X-XX; Manufacturer Part G6K-2F-Y-TR DC5; LCSC Part Name G6K-2F-Y-TR DC5
L401: 100nH; L_0603; LCSC C98088
NT401: NetTie_2; NetTie-2_SMD_Pad0.5mm
Q401, Q402, Q403, Q404, Q405: BC846B; Q_SOT-23; Part BC846B; LCSC C20069134
R401, R419, R420: 4.7kΩ; R_0603; Overload Voltage (Max) 75V; Tolerance ±1%; Part 0603WAF4701T5E; LCSC C23162
R402, R405, R409: 15Ω; R_0603; Overload Voltage (Max) 75V; Tolerance ±1%; Part 0603WAF150JT5E; LCSC C22810
R403: 100kΩ; R_0603; Overload Voltage (Max) 75V; Tolerance ±1%; Part 0603WAF1003T5E; LCSC C25803
R404: 270Ω; R_0805; Overload Voltage (Max) 150V; Tolerance ±1%; Part 0805W8F2700T5E; LCSC C17590
R406: 4.7Ω; R_0603; Overload Voltage (Max) 75V; Tolerance ±1%; Part 0603WAF470KT5E; LCSC C23164
R407: 4.3kΩ; R_0603; Overload Voltage (Max) 75V; Tolerance ±1%; Part 0603WAF4301T5E; LCSC C23159
R408, R433, R434, R437, R438, R439: 3.3kΩ; R_0603; Overload Voltage (Max) 75V; Tolerance ±1%; Part 0603WAF3301T5E; LCSC C22978
R410, R413: 100Ω; R_1206; Overload Voltage (Max) 200V; Tolerance ±1%; Part 1206W4F1000T5E; LCSC C17901
R414, R415, R416, R417: 10Ω; R_0603; Overload Voltage (Max) 75V; Tolerance ±1%; Part 0603WAF100JT5E; LCSC C22859
R418, R421, R432, R460: 180Ω; R_0603; Overload Voltage (Max) 75V; Tolerance ±1%; Part 0603WAF1800T5E; LCSC C22828
R422, R423, R424, R425: 100Ω; R_0603; Overload Voltage (Max) 75V; Tolerance ±1%; Part 0603WAF1000T5E; LCSC C22775
R426: 47Ω; R_0603; Overload Voltage (Max) 75V; Tolerance ±1%; Part 0603WAF470JT5E; LCSC C23182
R427, R428: 390Ω; R_0603; Overload Voltage (Max) 75V; Tolerance ±1%; Part 0603WAF3900T5E; LCSC C23151
R429: 6.8kΩ; R_0603; Overload Voltage (Max) 75V; Tolerance ±1%; Part 0603WAF6801T5E; LCSC C23212
R430, R431: 56Ω; R_0603; Overload Voltage (Max) 75V; Tolerance ±1%; Part 0603WAF560JT5E; LCSC C25196
R435, R436, R440, R441, R442: 22kΩ; R_0603; Overload Voltage (Max) 75V; Tolerance ±1%; Part 0603WAF2202T5E; LCSC C31850
R443, R444, R445, R446, R447: 68Ω; R_0603; Overload Voltage (Max) 75V; Tolerance ±1%; Part 0603WAF680JT5E; LCSC C27592
R455: 82Ω; R_0603; Overload Voltage (Max) 75V; Tolerance ±1%; Part 0603WAF820JT5E; LCSC C23255
R457: 120Ω; R_1206; Overload Voltage (Max) 200V; Tolerance ±1%; Part 1206W4F1200T5E; LCSC C17909
R458: 1.8kΩ; R_0603; Overload Voltage (Max) 75V; Tolerance ±1%; Part 0603WAF1801T5E; LCSC C4177
U301: OPA2673IRGVR; Texas_RSA_VQFN-16-1EP_4x4mm_P0.65mm_EP2.7x2.7mm; LCSC C1848168
U303: NE5532DR; SOIC-8_L4.9-W3.9-P1.27-LS6.0-BL; Part NE5532DR; LCSC C7426

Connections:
+6V5: R443.1, R444.1, R445.1, R446.1, R447.1; also elsewhere on the board
+6V5_OPA: D402.2, D405.2; also elsewhere on the board
+6V5_OPA2: D401.2; also elsewhere on the board
-6V5_OPA: D402.1, D405.1; also elsewhere on the board
-6V5_OPA2: D401.1; also elsewhere on the board
/DAC/DAC_OUT: D405.3, R432.1, R460.2; also elsewhere on the board
/GainOffsetStage/OUT_PROT: K4.6, K5.3; also elsewhere on the board
/K1: R437.2; also elsewhere on the board
/K2: R438.2; also elsewhere on the board
/K3: R439.2; also elsewhere on the board
/K4_OUT_AMPLIFIER: R433.2; also elsewhere on the board
/K5_ON_OUT: R434.2; also elsewhere on the board
/OFFSETS: R408.2; also elsewhere on the board
/OUT: C408.1, L401.2; also elsewhere on the board
GND: C402.2, C403.2, C404.2, C405.2, C406.1, C407.2, C408.2, C409.1, C410.1, C411.1, C412.1, C413.1, Q401.2 (E), Q402.2 (E), Q403.2 (E), Q404.2 (E), Q405.2 (E), R403.2, R407.2, R409.2, R414.1, R415.1, R416.1, R417.1, R418.1, R419.1, R420.1, R421.1, R435.2, R436.2, R440.2, R441.2, R442.2; also elsewhere on the board
unnamed: C402.1, C403.1, C404.1, C405.1, D401.3, R401.2, R406.2, R457.1, R458.1
unnamed: C407.1, K5.6, L401.1
unnamed: C409.2, D403.3, K4.1, R447.2
unnamed: C410.2, D404.3, K5.1, R446.2
unnamed: C411.2, D406.3, K1.1, R443.2
unnamed: C412.2, D407.3, K2.1, R444.2
unnamed: C413.2, D408.3, K3.1, R445.2
unnamed: D402.3, R404.2, R410.2, R413.2, U301.16
unnamed: K1.2, K1.7
unnamed: K1.3, R432.2, R460.1
unnamed: K1.4, R418.2, R419.2, R426.1
unnamed: K1.5, R420.2, R421.2, R429.2, R455.2
unnamed: K1.6, K2.3
unnamed: K2.2, K2.7
unnamed: K2.4, R422.2, R427.1
unnamed: K2.5, R423.2, R430.2
unnamed: K2.6, K3.3
unnamed: K3.2, K3.7
unnamed: K3.4, R424.2, R428.1
unnamed: K3.5, R425.2, R431.2
unnamed: K3.6, NT401.1, R457.2, R458.2
unnamed: K4.2, K4.7
unnamed: K4.3, NT401.2
unnamed: K4.4, R402.1, R403.1
unnamed: K4.5, R410.1, R413.1
unnamed: K5.4, K5.5
unnamed: Q401.1 (B), R433.1, R435.1
unnamed: D403.1, K4.8, Q401.3 (C)
unnamed: Q402.1 (B), R434.1, R436.1
unnamed: D404.1, K5.8, Q402.3 (C)
unnamed: Q403.1 (B), R437.1, R440.1
unnamed: D406.1, K1.8, Q403.3 (C)
unnamed: Q404.1 (B), R438.1, R441.1
unnamed: D407.1, K2.8, Q404.3 (C)
unnamed: Q405.1 (B), R439.1, R442.1
unnamed: D408.1, K3.8, Q405.3 (C)
unnamed: R405.2, R409.1
unnamed: R414.2, R422.1
unnamed: R415.2, R423.1
unnamed: R416.2, R424.1
unnamed: R417.2, R425.1
unnamed: R426.2, R429.1, R455.1
unnamed: R427.2, R430.1
unnamed: R428.2, R431.1
unnamed: R402.2, U301.3 (+)
unnamed: R404.1, R405.1, U301.2 (-)
unnamed: C406.2, R408.1, U303.5 (IN2+)
unnamed: C401.2, R401.1, R407.1, U303.6 (IN2-)
unnamed: C401.1, R406.1, U303.7 (OUT2)

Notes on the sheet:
PI-Pads:
Gain: +20dB
112.5Ω
Gain: -20dB
2,171V at 2V Offset
fg=2.2kHz Z (20µF @ 2.2kHz) = 3.6 Ohm
90Ω
Gain: -10dB
-20dB A=0.1: 110 / 445,5 / 110 -10dB A=sqrt(0.1): 173,25 / 128,07 / 173,25

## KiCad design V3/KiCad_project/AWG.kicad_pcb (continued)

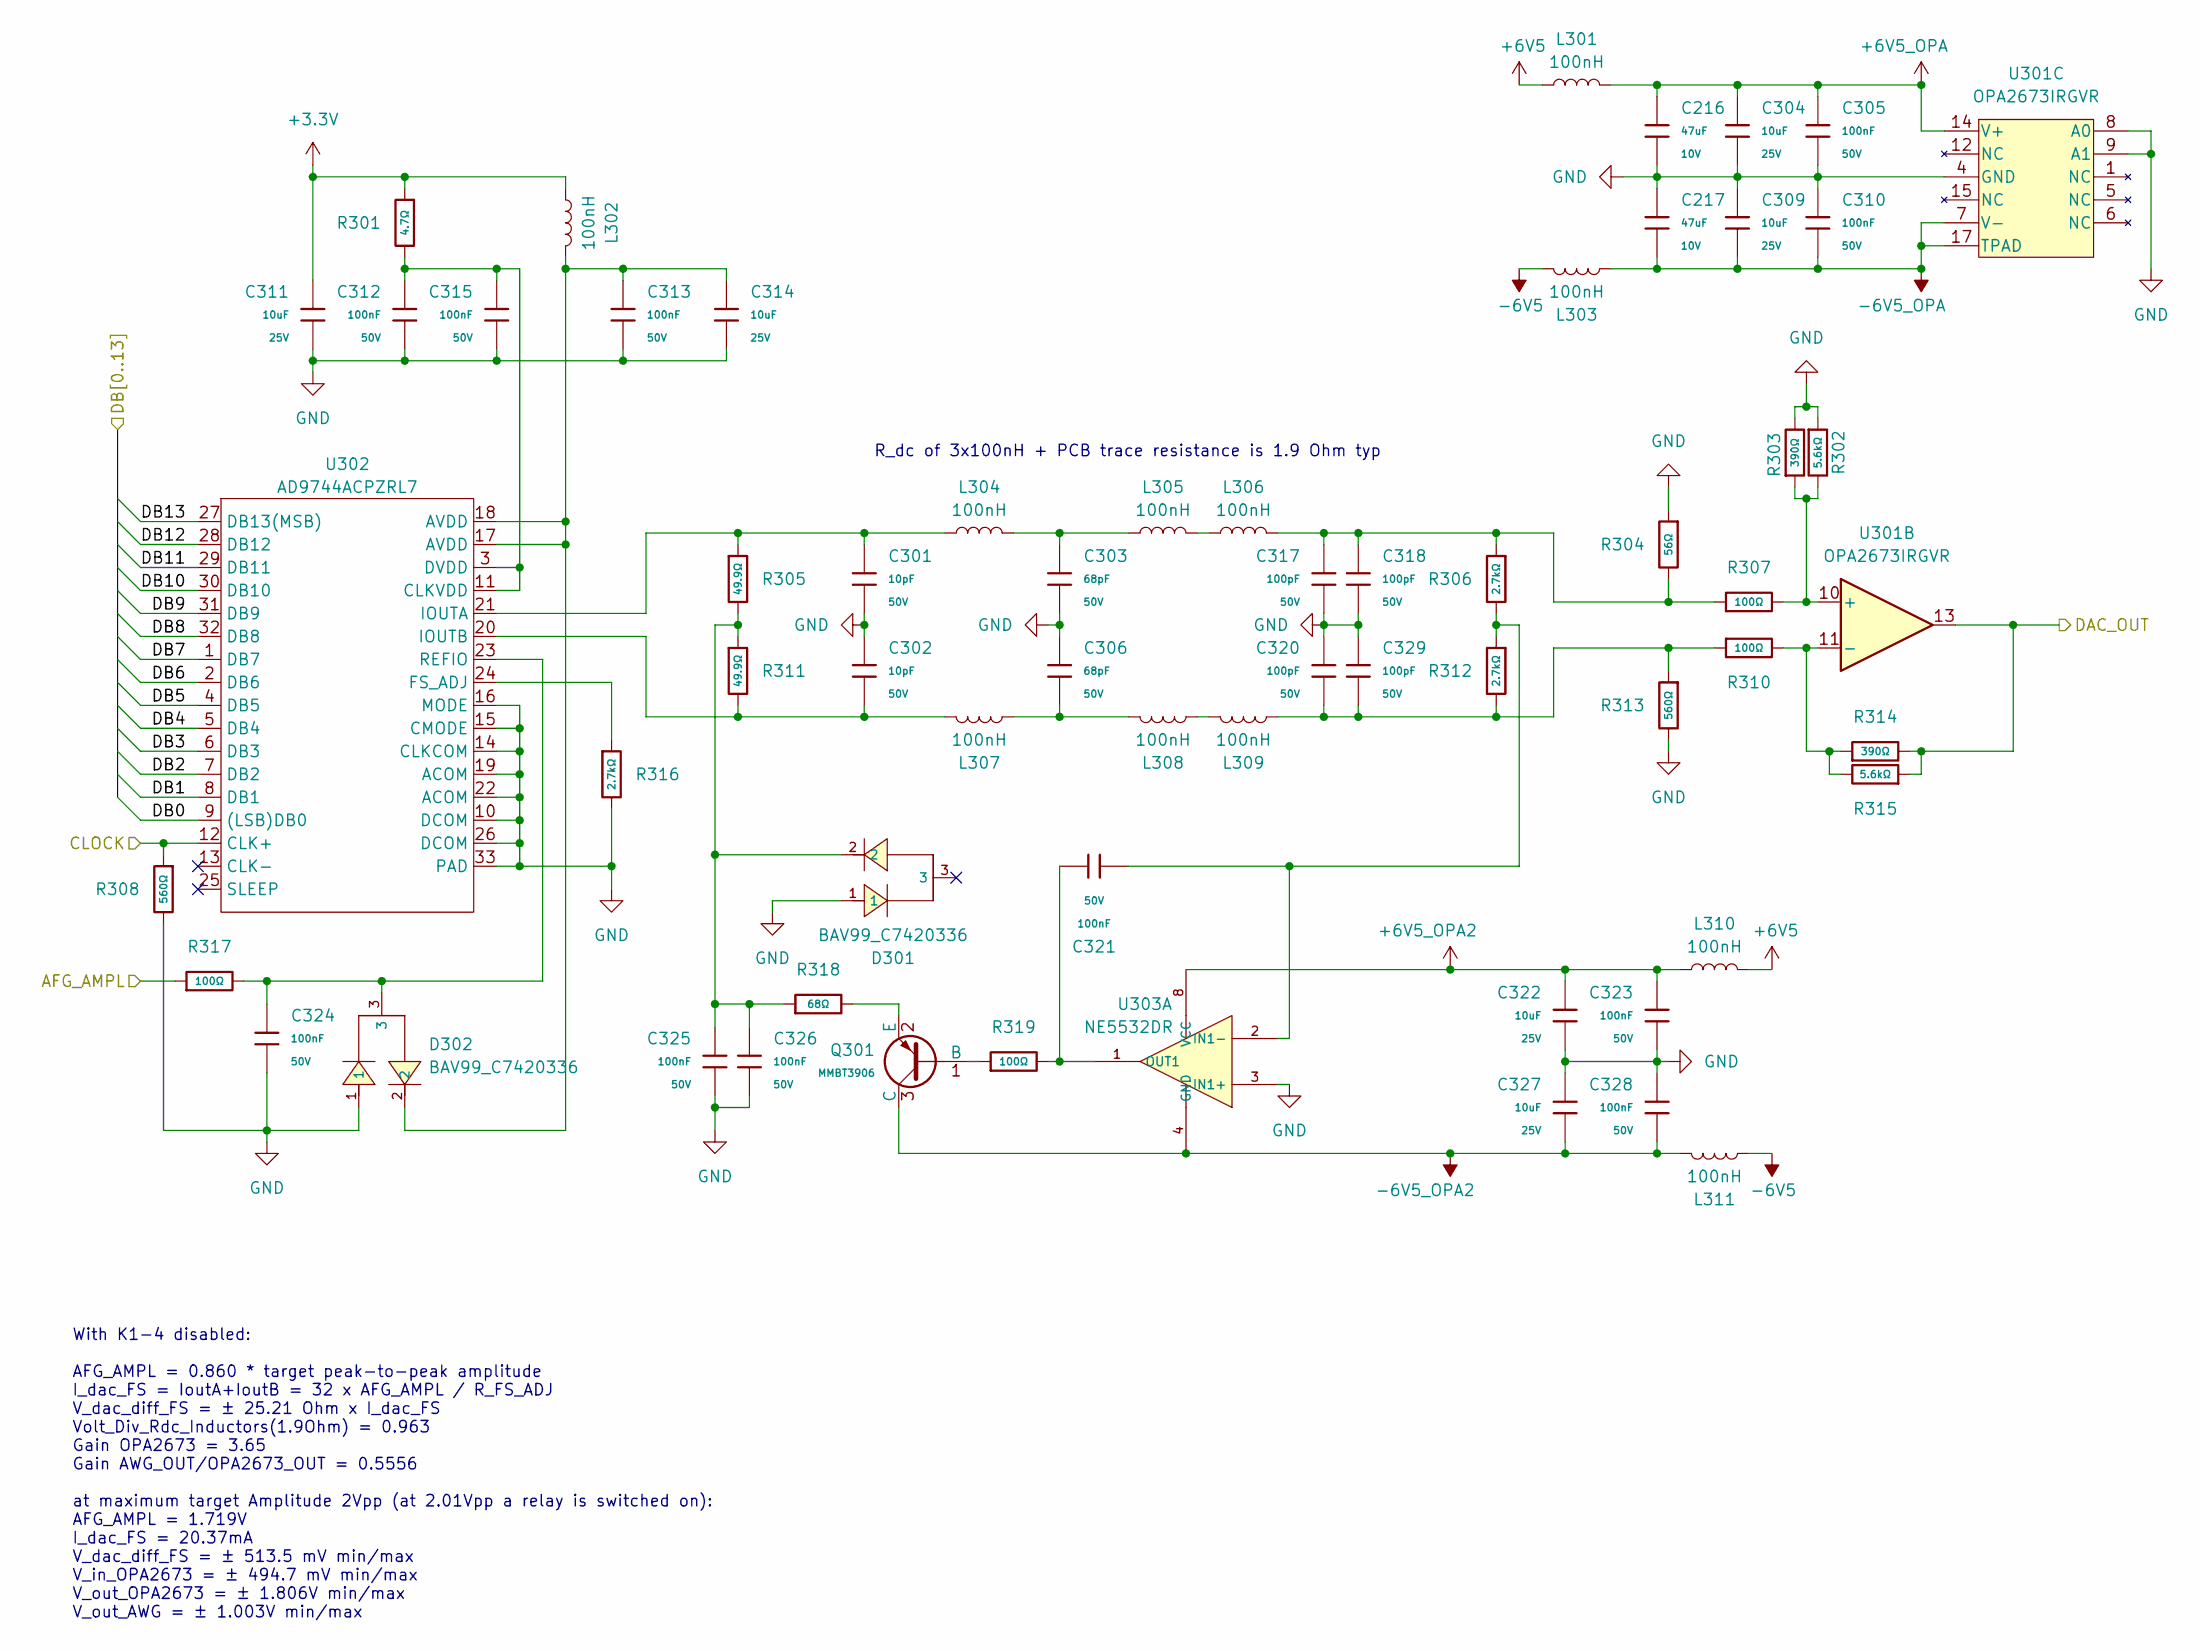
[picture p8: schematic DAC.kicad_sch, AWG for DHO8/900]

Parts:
C216, C217: 47uF; C_1206; Voltage Rated 10V; Tolerance ±20%; Part CL31A476MPHNNNE; LCSC C96123
C301, C302: 10pF; C_0603; Voltage Rated 50V; Tolerance ±5%; Part CL10C100JB8NNNC; LCSC C1634
C303, C306: 68pF; C_0603; Voltage Rated 50V; Tolerance ±5%; Part CL10C680JB8NNNC; LCSC C28262
C304, C309, C311, C314, C322, C327: 10uF; C_0805; Voltage Rated 25V; Tolerance ±10%; Part CL21A106KAYNNNE; LCSC C15850
C305, C310, C312, C313, C315, C321, C323, C324, C325, C326, C328: 100nF; C_0603; Voltage Rated 50V; Tolerance ±10%; Part CC0603KRX7R9BB104; LCSC C14663
C317, C318, C320, C329: 100pF; C_0603; Voltage Rated 50V; Tolerance ±5%; Part CL10C101JB8NNNC; LCSC C14858
D301, D302: BAV99_C7420336; SOT-23-3_L2.9-W1.3-P1.90-LS2.4-BR; Reverse Voltage (Vr) 100V; Forward Voltage (Vf@If) 1.25V@150mA; Part BAV99; LCSC C7420336
L301, L302, L303, L304, L305, L306, L307, L308, L309, L310, L311: 100nH; L_0603; LCSC C98088
Q301: MMBT3906; Q_SOT-23; Part MMBT3906; LCSC C7420354
R301: 4.7Ω; R_0603; Overload Voltage (Max) 75V; Tolerance ±1%; Part 0603WAF470KT5E; LCSC C23164
R302, R315: 5.6kΩ; R_0603; Overload Voltage (Max) 75V; Tolerance ±1%; Part 0603WAF5601T5E; LCSC C23189
R303, R314: 390Ω; R_0603; Overload Voltage (Max) 75V; Tolerance ±1%; Part 0603WAF3900T5E; LCSC C23151
R304: 56Ω; R_0603; Overload Voltage (Max) 75V; Tolerance ±1%; Part 0603WAF560JT5E; LCSC C25196
R305, R311: 49.9Ω; R_0603; Overload Voltage (Max) 75V; Tolerance ±1%; Part 0603WAF499JT5E; LCSC C23185
R306, R312, R316: 2.7kΩ; R_0603; Overload Voltage (Max) 75V; Tolerance ±1%; Part 0603WAF2701T5E; LCSC C13167
R307, R310, R317, R319: 100Ω; R_0603; Overload Voltage (Max) 75V; Tolerance ±1%; Part 0603WAF1000T5E; LCSC C22775
R308, R313: 560Ω; R_0603; Overload Voltage (Max) 75V; Tolerance ±1%; Part 0603WAF5600T5E; LCSC C23204
R318: 68Ω; R_0603; Overload Voltage (Max) 75V; Tolerance ±1%; Part 0603WAF680JT5E; LCSC C27592
U301: OPA2673IRGVR; Texas_RSA_VQFN-16-1EP_4x4mm_P0.65mm_EP2.7x2.7mm; LCSC C1848168
U302: AD9744ACPZRL7; LFCSP-32_L5.0-W5.0-P0.50-BL-EP3.1; Manufacturer Part AD9744ACPZRL7; LCSC Part Name AD9744ACPZRL7
U303: NE5532DR; SOIC-8_L4.9-W3.9-P1.27-LS6.0-BL; Part NE5532DR; LCSC C7426

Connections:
+3.3V: C311.1, L302.1, R301.1; also elsewhere on the board
+6V5: L301.2, L310.1; also elsewhere on the board
+6V5_OPA: C216.2, C304.1, C305.1, L301.1, U301.14 (V+); also elsewhere on the board
+6V5_OPA2: C322.1, C323.1, L310.2, U303.8 (VCC); also elsewhere on the board
-6V5: L303.2, L311.1; also elsewhere on the board
-6V5_OPA: C217.1, C309.2, C310.2, L303.1, U301.7 (V-), U301.17 (TPAD); also elsewhere on the board
-6V5_OPA2: C327.2, C328.2, L311.2, Q301.3 (C), U303.4 (GND); also elsewhere on the board
/AFG_AMPL: R317.1; also elsewhere on the board
/CLOCK: R308.1, U302.12 (CLK+); also elsewhere on the board
/DAC/DAC_OUT: R314.2, R315.1, U301.13; also elsewhere on the board
/DB0: U302.9 ((LSB)DB0); also elsewhere on the board
/DB1: U302.8 (DB1); also elsewhere on the board
/DB2: U302.7 (DB2); also elsewhere on the board
/DB3: U302.6 (DB3); also elsewhere on the board
/DB4: U302.5 (DB4); also elsewhere on the board
/DB5: U302.4 (DB5); also elsewhere on the board
/DB6: U302.2 (DB6); also elsewhere on the board
/DB7: U302.1 (DB7); also elsewhere on the board
/DB8: U302.32 (DB8); also elsewhere on the board
/DB9: U302.31 (DB9); also elsewhere on the board
/DB10: U302.30 (DB10); also elsewhere on the board
/DB11: U302.29 (DB11); also elsewhere on the board
/DB12: U302.28 (DB12); also elsewhere on the board
/DB13: U302.27 (DB13(MSB)); also elsewhere on the board
GND: C216.1, C217.2, C301.2, C302.1, C303.2, C304.2, C305.2, C306.1, C309.1, C310.1, C311.2, C312.2, C313.2, C314.2, C315.2, C317.2, C318.2, C320.1, C322.2, C323.2, C324.2, C325.2, C326.2, C327.1, C328.1, C329.1, D301.1, D302.1, R302.1, R303.2, R304.1, R308.2, R313.2, R316.2, U301.4 (GND), U301.8 (A0), U301.9 (A1), U302.10 (DCOM), U302.14 (CLKCOM), U302.15 (CMODE), U302.16 (MODE), U302.19 (ACOM), U302.22 (ACOM), U302.26 (DCOM), U302.33 (PAD), U303.3 (IN1+); also elsewhere on the board
unnamed: C303.1, L304.2, L305.1
unnamed: C306.2, L307.2, L308.1
unnamed: C313.1, C314.1, D302.2, L302.2, U302.17 (AVDD), U302.18 (AVDD)
unnamed: C317.1, C318.1, L306.2, R304.2, R306.1, R307.1
unnamed: C320.2, C329.2, L309.2, R310.1, R312.2, R313.1
unnamed: C325.1, C326.1, D301.2, R305.2, R311.1, R318.1
unnamed: L305.2, L306.1
unnamed: L308.2, L309.1
unnamed: Q301.1 (B), R319.1
unnamed: Q301.2 (E), R318.2
unnamed: R302.2, R303.1, R307.2, U301.10 (+)
unnamed: R310.2, R314.1, R315.2, U301.11 (-)
unnamed: C312.1, C315.1, R301.2, U302.3 (DVDD), U302.11 (CLKVDD)
unnamed: R316.1, U302.24 (FS_ADJ)
unnamed: C301.1, L304.1, R305.1, U302.21 (IOUTA)
unnamed: C302.2, L307.1, R311.2, U302.20 (IOUTB)
unnamed: C324.1, D302.3, R317.2, U302.23 (REFIO)
unnamed: C321.2, R306.2, R312.1, U303.2 (IN1-)
unnamed: C321.1, R319.2, U303.1 (OUT1)

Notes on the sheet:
With K1-4 disabled: AFG_AMPL = 0.860 * target peak-to-peak amplitude I_dac_FS = IoutA+IoutB = 32 x AFG_AMPL / R_FS_ADJ V_dac_diff_FS = ± 25.21 Ohm x I_dac_FS Volt_Div_Rdc_Inductors(1.9Ohm) = 0.963 Gain OPA2673 = 3.65 Gain AWG_OUT/OPA2673_OUT = 0.5556 at maximum target Amplitude 2Vpp (at 2.01Vpp a r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
R_dc of 3x100nH + PCB trace resistance is 1.9 Ohm typ

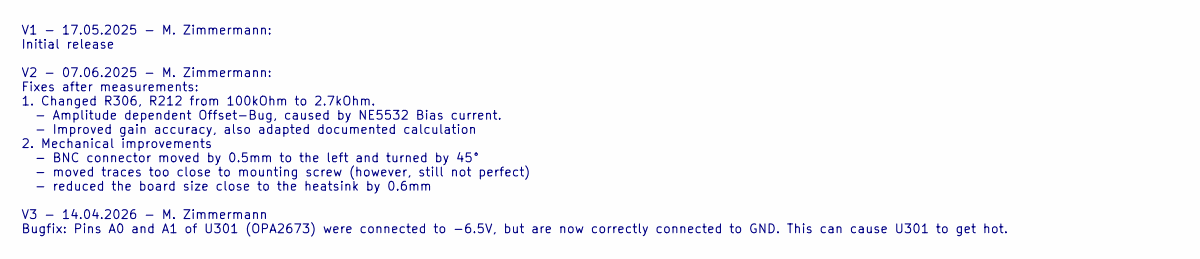
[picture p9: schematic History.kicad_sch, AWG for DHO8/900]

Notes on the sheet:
V1 - 17.05.2025 - M. Zimmermann: Initial release V2 - 07.06.2025 - M. Zimmermann: Fixes after measurements: 1. Changed R306, R212 from 100kOhm to 2.7kOhm. - Amplitude dependent Offset-Bug, caused by NE5532 Bias current. - Improved gain accuracy, also adapted documented calculation 2. Mechanical imp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

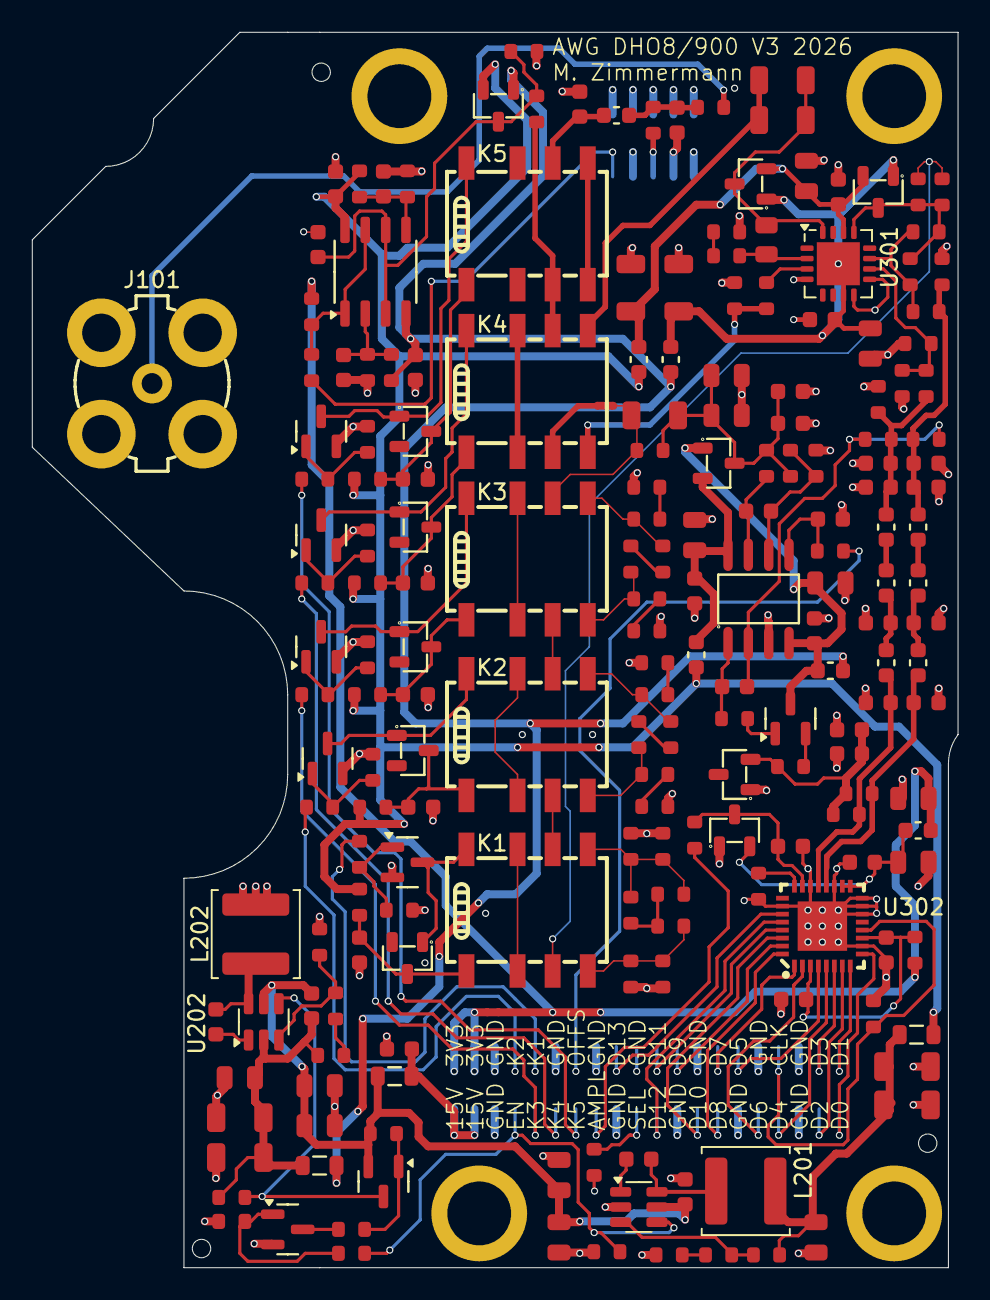
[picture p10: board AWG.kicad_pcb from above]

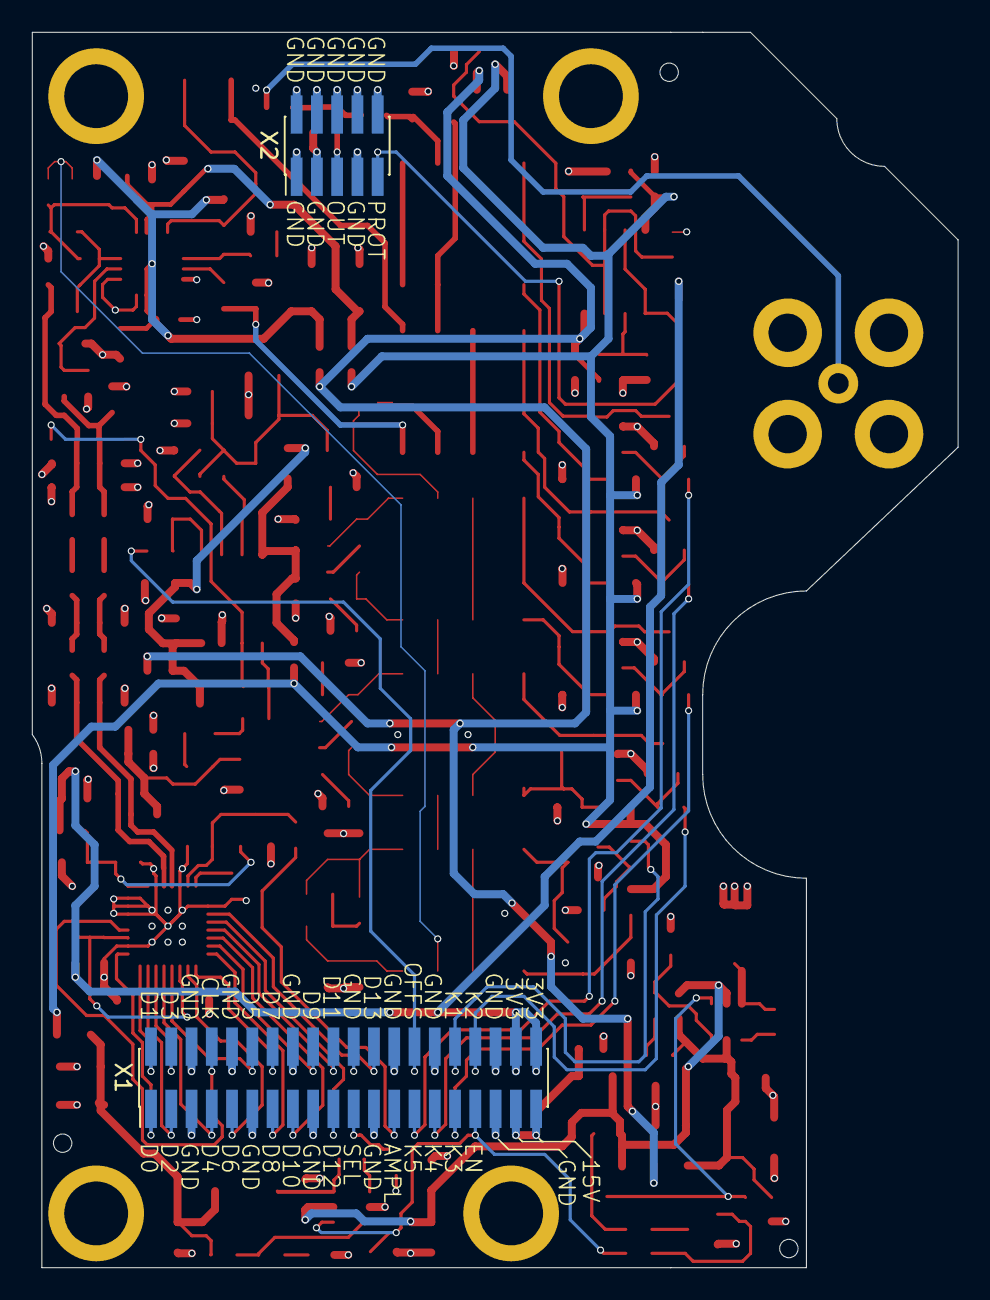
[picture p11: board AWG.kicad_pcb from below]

Board: 4 copper layers, 58.0 x 77.4 mm, 208 parts (2 on the bottom side), 126 nets.

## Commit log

2025-06-07 Initial commit, V1 and V2
    Version 1: ordered and tested, but contains bugs (see history in V2 schematic)
    Version 2: bugs from V1 fixed, but new Gerber files are not tested
    [AWG.kicad_pcb, AWG.kicad_sch, DAC.kicad_sch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]
2025-06-14 Update README.md, corrected sample frequency
2025-06-29 Update README.md: Removed version resistor requirement
2025-07-16 Fix rotation for JLCPCB
    Add `FT Rotation Offset` fields to components that have a wrong
    rotation when ordering from JLCPCB.
    [AWG.kicad_pcb, DAC.kicad_sch, GainOffsetStage.kicad_sch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]
2025-08-07 Silkscreen convenience improvements
    * show BNC lug orientation
    * label connectors on bottom layer
    [AWG.kicad_pcb]
2025-09-14 Added ordering number to value of U201, U202 and U302 because it did not appear in schematic.pdf and in bom.csv
    [AWG.kicad_pcb, DAC.kicad_sch, PSUP.kicad_sch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]
2026-04-14 Added V3.
    [AWG.kicad_pcb, AWG.kicad_sch, DAC.kicad_sch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]
